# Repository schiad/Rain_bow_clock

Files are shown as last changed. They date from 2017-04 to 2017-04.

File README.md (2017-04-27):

   ╔════════════════════╗ ╔════════════════════╗ ╔════════════════════╗ ╔════════════════════╗
   ║JEUDI    01 JAN 1970║ ║01/01/1970  00:03:00║ ║01/01/1970  00:28:33║ ║JEUDI    01 JAN 1970║
   ║                    ║ ║←       HELP       →║ ║   Neopixel Hello   ║ ║                    ║
   ║      00:59:58      ║ ║--------------------║ ║>   Crash Clock    <║ ║01/01/1970  00:00:00║
   ║                    ║ ║Obtain usage advice.║ ║     Toggle LCD     ║ ║                    ║
   ╚════════════════════╝ ╚════════════════════╝ ╚════════════════════╝ ╚════════════════════╝

# Rainbow Clock Project Pinout

      ______________________________________________________________________________________
     |      Module      |   Pins    |        Pin designator(s)       |        Notes         |
     |__________________|___________|________________________________|______________________|
     | 1x Temperature   |         2 | SCL1, SDA1                     | Uses I2C.            |
     |__________________|___________|________________________________|______________________|
     | 1x Bluetooth     |         2 | RPB6*, RPA0*                   | Uses UART.           |
     |__________________|___________|________________________________|______________________|
     | 1x Led strip     |         1 | RC4                            | Single pin, 60 leds. |
     |__________________|___________|________________________________|______________________|
     | 1x LCD Screen    |        10 | RB10..RB15, RC0, RC1, RB2, RB3 | xxxxxxxxxxxxxxxxxxxx |
     |__________________|___________|________________________________| xxxxxxxxxxxxxxxxxxxx |
     | 1x Light sensor  |         1 | AN1                            | xxxxxxxxxxxxxxxxxxxx |
     |__________________|___________|________________________________| xxxxxxxxxxxxxxxxxxxx |
     | 1x ICD           |         3 | PGEC1, PGED1, MCLR             | xxxxxxxxxxxxxxxxxxxx |
     |__________________|___________|________________________________|______________________|
     | 1x LCD Backlight |         1 | RPC7*                          | Uses Output compare. |
     |__________________|___________|________________________________|______________________|
     | 3x Button        |     3 + 1 | INT0, RPC2*, RPC3*, RPC8*      | Uses NMI.            |
     |__________________|___________|________________________________|______________________|
     | 1x 8MHz Osc.     |         2 | OSC1, OSC2                     | xxxxxxxxxxxxxxxxxxxx |
     |__________________|___________|________________________________|______________________|
     | 1x 32kHz Osc.    |         2 | SOSCI, SOSCO                   | For the RTC.         |
     |__________________|___________|________________________________|______________________|
     | xxxxxxxxxxxxxxxx |         1 | RPC5*                          | Neopixel debug pin.  |
     |__________________|___________|________________________________|______________________|
     |        Total: 12 | Total: 29 |
     |__________________|___________|

     * pin is remappable for a function (Output compare, UART, SPI, NMI, etc...)

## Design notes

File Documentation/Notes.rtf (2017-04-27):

╔════════════════════╗
║JEUDI 01 JAN 1970║
║ ║
║ 00:59:58 ║
║ ║
╚════════════════════╝

╔════════════════════╗
║01/01/1970 00:03:00║
║← HELP →║
║--------------------║
║Obtain usage advice.║
╚════════════════════╝

╔════════════════════╗
║01/01/1970 00:15:17║
║ Neopixel Hello ║
║> Crash Clock <║
║ Toggle LCD ║
╚════════════════════╝

╔════════════════════╗
║01/01/1970 00:28:33║
║ ║
║01/01/1970 00:00:00║
║ ║
╚════════════════════╝

╔════════════════════╗
║01/01/1970 00:15:17║
║ Changing colors ║
║> Bluetooth sync <║
║ Setting the time ║
╚════════════════════╝

╔════════════════════╗
║Oops! That's a crash║
║Prepare for a reboot║
║EPC : 0x9D003EF8 ║
║Bus error ld/st ║
╚════════════════════╝

╔════════════════════╗
║01/01/1970 00:00:39║
║ ║
║01 01 0001 00 00 00║
║ d M Y h m s║
╚════════════════════╝

╚═MAIN═╗
╠═ABOUT═══╗
║ ╚═<plain template>
║
╠═ACTIONS═╗
║ ╠═Toggle_LCD
║ ╠═Crash_Clock
║ ╠═Neopixel_Hello
║ ╠═Reset_Clock
║ ╚═Say_Hello
║
╠═HELP════╗
║ ╠═Setting_the_time═╗
║ ║ ╚═<plain_template>
║ ║
║ ╠═Bluetooth_sync═══╗
║ ║ ╚═<plain_template>
║ ║
║ ╚═Changing_colors══╗
║ ╚═<plain_template>
╠═COLORS══╗
║ ╠═Background═══════╗
║ ║ ╚═<edit_template>
║ ║
║ ╠═Foreground═══════╗
║ ║ ╚═<edit_template>
║ ║
║ ╚═Markers══════════╗
║ ╚═<edit_template>
╚═TIME════╗
╚═<edit_template>

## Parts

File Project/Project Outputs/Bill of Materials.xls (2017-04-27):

Comment | Description | Footprint | Quantity | Fabricant | Fournisseur | RefFabricant | RefFournisseur
0.47uF | Capacitor | CAP0603 | 1
1-215876-3 | Tyco 1-215876-3 | 1-215876-3 | 1 | TE Connectivity | Farnell | 1-215876-3 | 1773039
10uF | Capacitor | CAP0603 | 1
1K | Inductor | IND0603 | 1 | Murata | Farnell | BLM18TG102TN1D | 1115051
1uF | Capacitor | CAP0603 | 1
22uF | Capacitor | CAP0603 | 1
32kHz XTAL | Crystal Oscillator | NCL38LF | 1 | Fox Electronics | Farnell | NC38LF-327 | 2064058
8MHz XTAL | Crystal Oscillator | FOXSLF/080-20 | 1 | Fox Electronics | Farnell | FOXSLF/080-20 | 2057960
AC to DC adapter | Power adapter |  | 1 | IDEAL POWER | Farnell | 25HK-AB-050A400-CP | 2334613
BMP280 | Temp. sensor |  | 1 | BOSCH |  | BMP280
EC11B152420G-STEC11B01 | Rotary encoder | EC11B152420G-STEC11B01 | 1 | ALPS | Farnell | EC11B152420G-STEC11B01 | 1191733
HC-06 | Bluetooth |  | 1 | Wavesen |  | HC-06
Header 16 | Header, 16-Pin | Header 16 | 1 | SAMTEC | Farnell | CES-116-01-T-S | 1667522
LDR | Photoresistor | VT935G | 1 | Excelitas Tech | Farnell | VT935G | 1652638
MC42003A6W-BNMLW | LCD | MC42004A6W-BNMLW | 1 | MIDAS | Farnell | MC42004A6W-BNMLW | 2063162
PIC32MX110F016D-I/PT | Microcontroller | PIC32MX110F016H-I/PT | 1 | Microchip | Farnell | PIC32MX110F016D-I/PT | 2057068
PWR2.5 | Low Voltage Power Supply Connector | MJ-179PH | 1 | MULTICOMP | Farnell | MJ-179PH | 1737246
TS2940CP-3.3 C5 | Voltage Regulator | TS2940CP-3.3 C5 | 1 | TAIWAN SEMICONDUCTOR | Farnell | TS2940CP-3.3 C5 | 7261390
15pF | Capacitor | CAP0603 | 2
27pF | Capacitor | CAP0603 | 2
3306P-1-203 | Trimpot | 3306P-1-202 | 2 | Bourns | Farnell | 3306P-1-203 | 108240
Header 6 | Header, 6-Pin | Header 6 | 2 | MULTICOMP | Farnell | 2212S-06SG-85 | 1593462
SW-PB | Switch | 1-1825027-4 | 2 | TE Connectivity | Farnell | 1-1825027-4 | 2468742
4.7K | Resistor | RES0603 | 3
1K | Resistor | RES0603 | 4
WS2012B | Neopixel | WS2812b | 60 | WorldSemi |  | WS2812b
100nF | Capacitor | CAP0603 | 63

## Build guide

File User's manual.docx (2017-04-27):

Rainbow Clock

Electronics

User’s manual

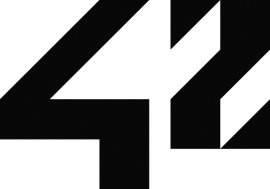
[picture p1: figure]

Document Revision. D

# Table of contents

# Glossary

## 1. Microcontroller

An embedded computer integrating a whole range of peripherals in a small package for convenience.

## 2. Bluetooth

A wireless communication standard permitting short-range exchange of data between electronic devices.

## 3. Refresh rate

A measure of the number of times an image can be drawn completely over the period of a second; this value is expressed in Hertz. Synonymous to “FPS”.

# Product overview

## 1. Description

Rainbow Clock is an unusual timekeeping device characterized by an exotic look and designed with electronics in mind.

## 2. Capabilities

- Display the current time of the day
- Synchronize itself via a Bluetooth connection
- Alter its color scheme depending on events

## 3. Quick specs

- Microcontroller: PIC32MZ series
- LEDs: 60, RGB type
- Refresh rate: ~10Hz
- Power: 15Watt max, 0.5Watt minimal, 0.6Watt typical (measured on a prototype)

# Basic operation

## 1. Reading the time of day

Each color encodes a distinct time unit. For each unit:

- 3 red adjacent LEDs represent the hours.
- 2 green adjacent LEDs represent the minutes.
- The remaining blue LED represents the seconds.

To ease reading, the clock’s display is subdivided in four quadrants.

## 4. Changing the color scheme

Using the central dial, navigate the menu looking for “Color Config.”

Validate your choice. You will be presented with a choice of colors on the screen. Use the dial again, select a color and validate your choice.

## 5. Updating the time on the clock

Using the central dial, navigate the menu looking for “Time Config.”

Validate your choice.

# Advanced operation

## 1. Synchronizing the clock using Bluetooth

Initiate a serial connection to the Rainbow Clock’s Bluetooth module configured for a rate of 115200 bauds. The code to be sent is structured as follows:

“TssmmhhddMMYYYY”

With ‘T’ designating the Time config function.

# Technical details

## 1. Block diagram

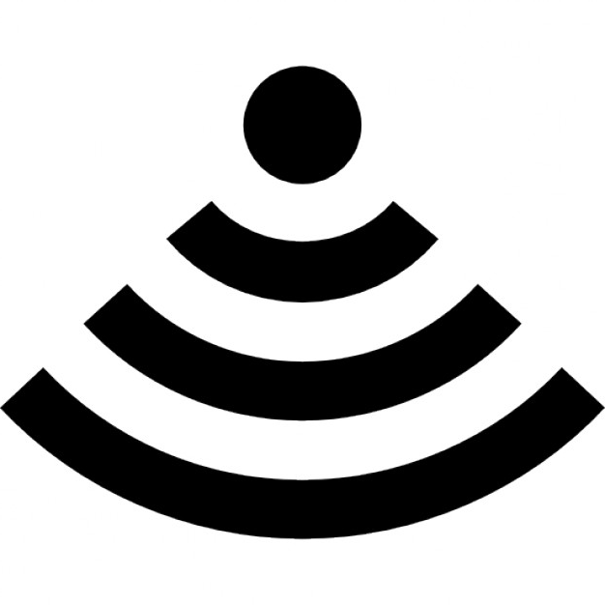
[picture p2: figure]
Afficher l'image d'origine
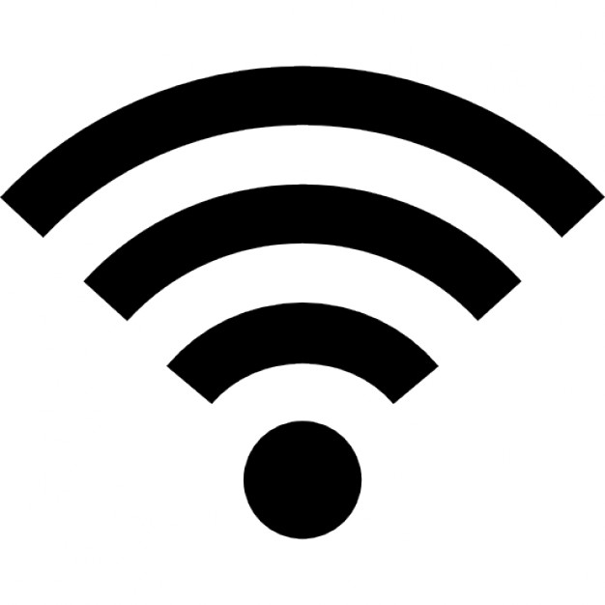
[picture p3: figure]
Afficher l'image d'origine

Light sensor (ADC)

Buzzer

(PWM)

PIC32

60 LEDs

(GPIO)

Bluetooth

(UART)

AC to DC Power supply

On/Off Button

Raspberry Pi *

Bluetooth

Smartphone *

Bluetooth

LCD Display
(GPIO)

Logging

(UART)

Buttons

(GPIO)

Temperature and pressure sensor (SPI)

## 4. Electrical consumption

- LEDs: Between 3.5V - 5.3V, about 60mA, 60mA x 60 = 3.6A max.
- PIC32: Between 2.3V - 3.6V, about 100mA.
- BMP280: Between 1.71V - 3.6V, about 4.2µA.
- RN4020: Between 3.0V – 3.6V, current is between 8mA 40mA.

In line 3.3V the consumption of current is about 141mA, in line 5V current consumption is about 3.6mA maximum, the total consumption is 3.741A maximum.

## 5. Components required for the project

- 1 (one) PIC32xxxxxx microcontroller. Ref: xxxxxxx
- 1 (one) Strip of 60 RGB LEDs. Ref fab: WS2812b
- 1 (one) Incremental rotary encoder Ref: 1191733
- 1 (one) 20x4 alphanumeric LCD screen Ref: 2063162
- x (xxx) Resistors xΩ Ref: xxxxxxx
- x (xxx) Capacitors xF Ref: xxxxxxx
- 1 (one) Voltage regulator Ref: xxxxxxx
- 1 (one) Digital pressure and temp sensor Ref fab: BMP280
- 1 (one) Bluetooth communication module Ref: 2442930
- 1 (one) 5v Supply Ref: xxxxxxx
- 1 (one) Photocell Ref: 7482280
- 1 (one) buzzer Ref: 2361105
- 2 (two) push buttons Ref: 1550267

…

We decided to use WS2812b as our LEDs for their convenience (They can be driven with a single wire using a simple protocol described in the datasheet of the component). (Not going to be bought from Farnell)

For our sensor, we chose the BMP280 or the BME280. It provides both temperature / pressure measurements and uses the I²C or SPI protocol. (Not going to be bought from Farnell).

A photoresistor will be used in a voltage divider setup, connected as an analog input pin.

We chose a rotary button for most of the interfacing with the clock. On the plus side, any watch user will figure out its multiples purposes.

Uses two GPIO plus two other GPIO buttons.

We are using a “Serial to Bluetooth” module for the device to communicate with smartphones and computers, so as to avoid the potential complexity of implementing a full Bluetooth stack, which we can’t afford at this time.

The chosen power supply can deliver up to 4A at 5v, and will still support the charge with all LED set at their maximum brightness level.

The chosen voltage regulator can deliver up to 1A in 3.3v for electronic modules using this amount of voltage.

## 6. Communications protocols used

### 1. UART

UART (or Serial) is a communication protocol, to use a same speed between PIC and Bluetooth we have choose 115200 bauds, in 8 bits mode, 1 Bit for stop, it will be used on Half Duplex mode.2.

### 2. I2C

The I2C protocol is essentially a bus made of 2 wires, SDA and SCL. SCL (serial clock line) is the clock speed for communication (the master imposes it), SDA (serial data line) is the line reserved for data transmissions.

I2C is a master-slave protocol. When a master starts to communicate, all others peripherals must stand by for instructions. The master first sends the starting bit, calling a slave peripheral by its address, before mentioning whether it wants to read or write data from it, then communicates the internal address of data.

For reading, the master sends SCL clock and reads back data sent by the slave peripheral via the SDA wire. If master is writing data in slave peripheral master will impose SCL clock and SDA data to write in slave. Of course each peripheral have a single addresses coded in 7 bits and each of them can be a master or slave.

### 3. SPI

The SPI protocol is a communication bus composed by 4 wires, SCLK (clock rate speed transfer), MOSI (communication from master to slave), MISO (communication for slave to master, and SS (slave selection).

The master selects a slave with SS wire by connect the line in GND, and initialize the communication with slave, master send data with MOSI line and slave respond with MISO line, slave and master can communicate in same time (full duplex communication).

## 7. Implementation

We want to make the rainbow clock really different of other clock we imagine to make it hexagonal form in front all LED’s and LCD display, in read all other components.

THU Mar 3 2016

PCB

LED

BUTTON

LCD

# Planned features

- Display basic weather data and forecast using built-in sensors

Data gathering could reveal itself being a nice addition to the project.

# Contributions

In alphabetical order:

- ltesson ltesson@student.42.fr
- nahmed-h nahmed-h@student.42.fr
- schiad schiad@student.42.fr
- vchesnea vchesnea@student.42.fr

Page layout by: vchesnea

# Endnotes

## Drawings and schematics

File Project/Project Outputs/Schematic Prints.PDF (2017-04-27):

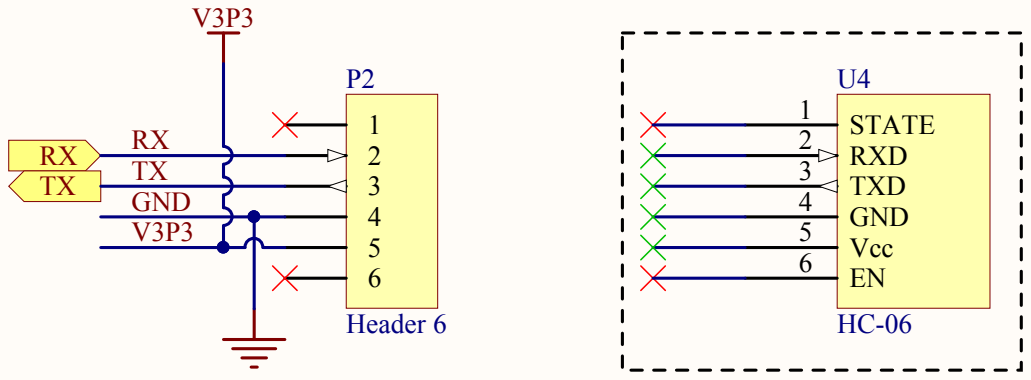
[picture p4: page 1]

Title | ****

Serial to Bluetooth module *

Size: A4 | Number: | Revision:
Date: 26/06/2016 Time: 15:38:15 | | Sheet * of

C:\Users\bocal\Desktop\RainbowClockV3\Project\Schematics\Bluetooth.SchDoc
File:

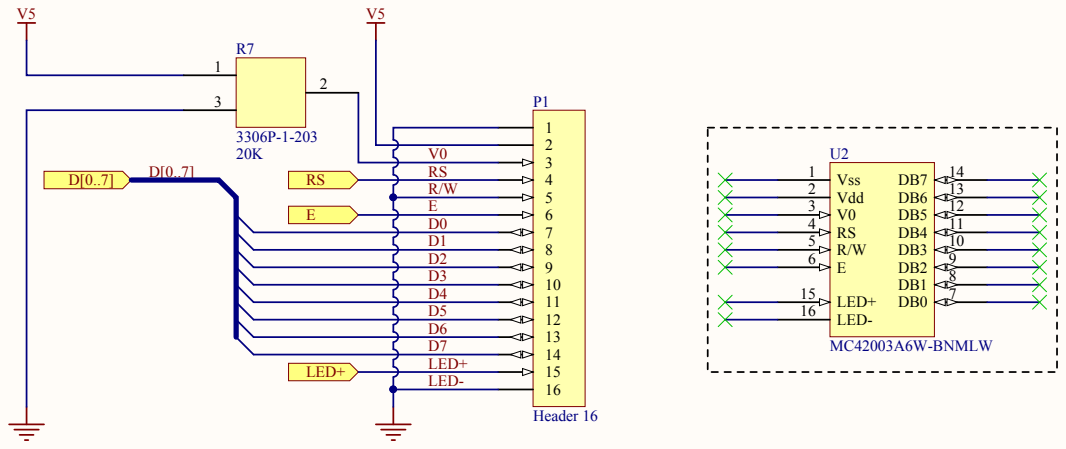
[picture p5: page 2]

C:\Users\bocal\Desktop\RainbowClockV3\Project\Schematics\LCD.SchDoc

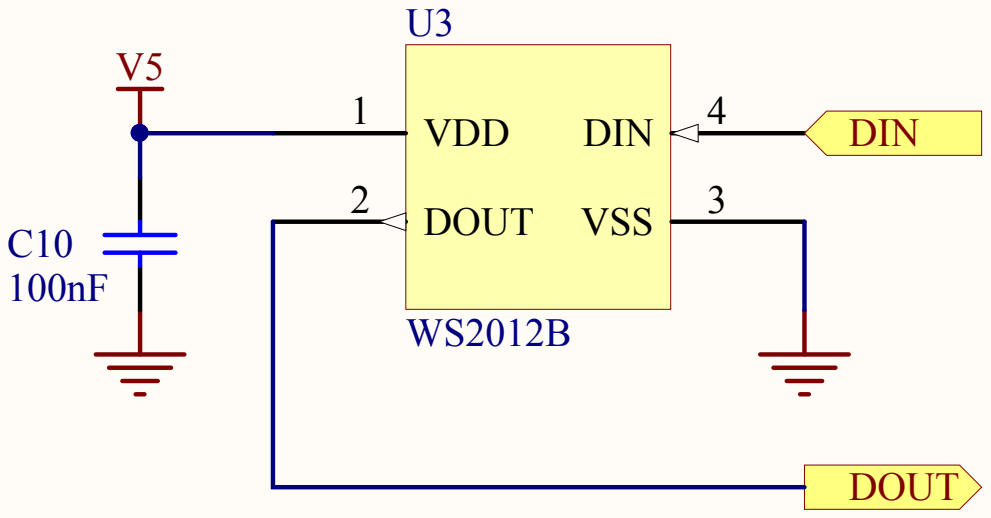
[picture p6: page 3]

Title Neopixel | * * *

C:\Users\bocal\Desktop\RainbowClockV3\Project\Schematics\Neopixel.SchDoc

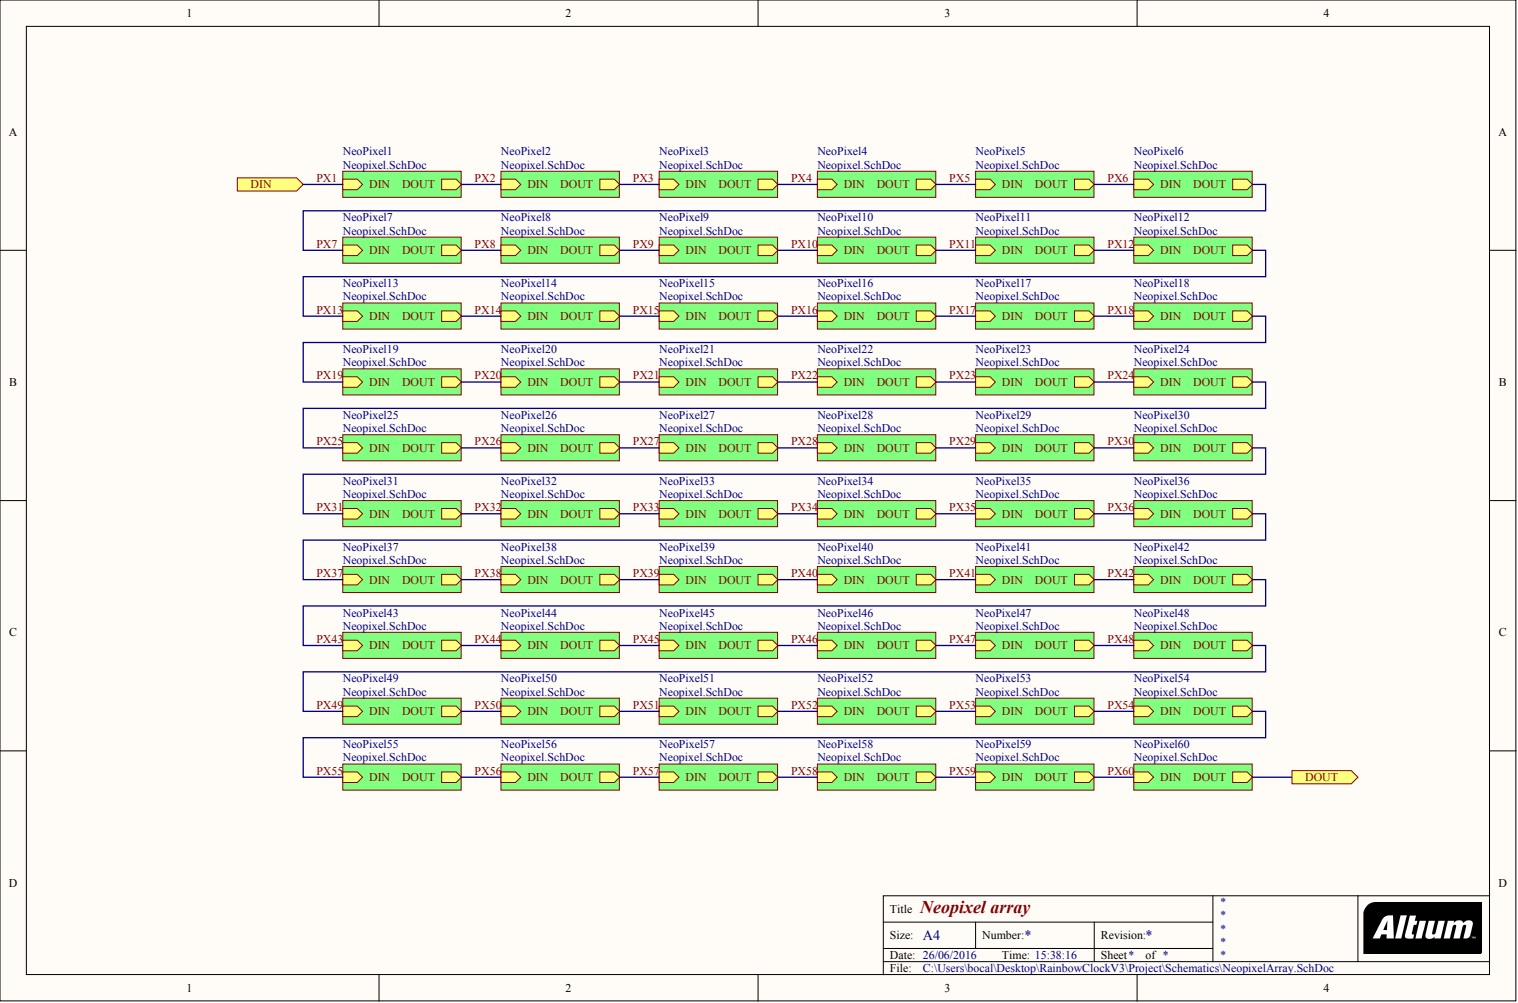
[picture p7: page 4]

Title Neopixel array | * * *

C:\Users\bocal\Desktop\RainbowClockV3\Project\Schematics\NeopixelArray.SchDoc

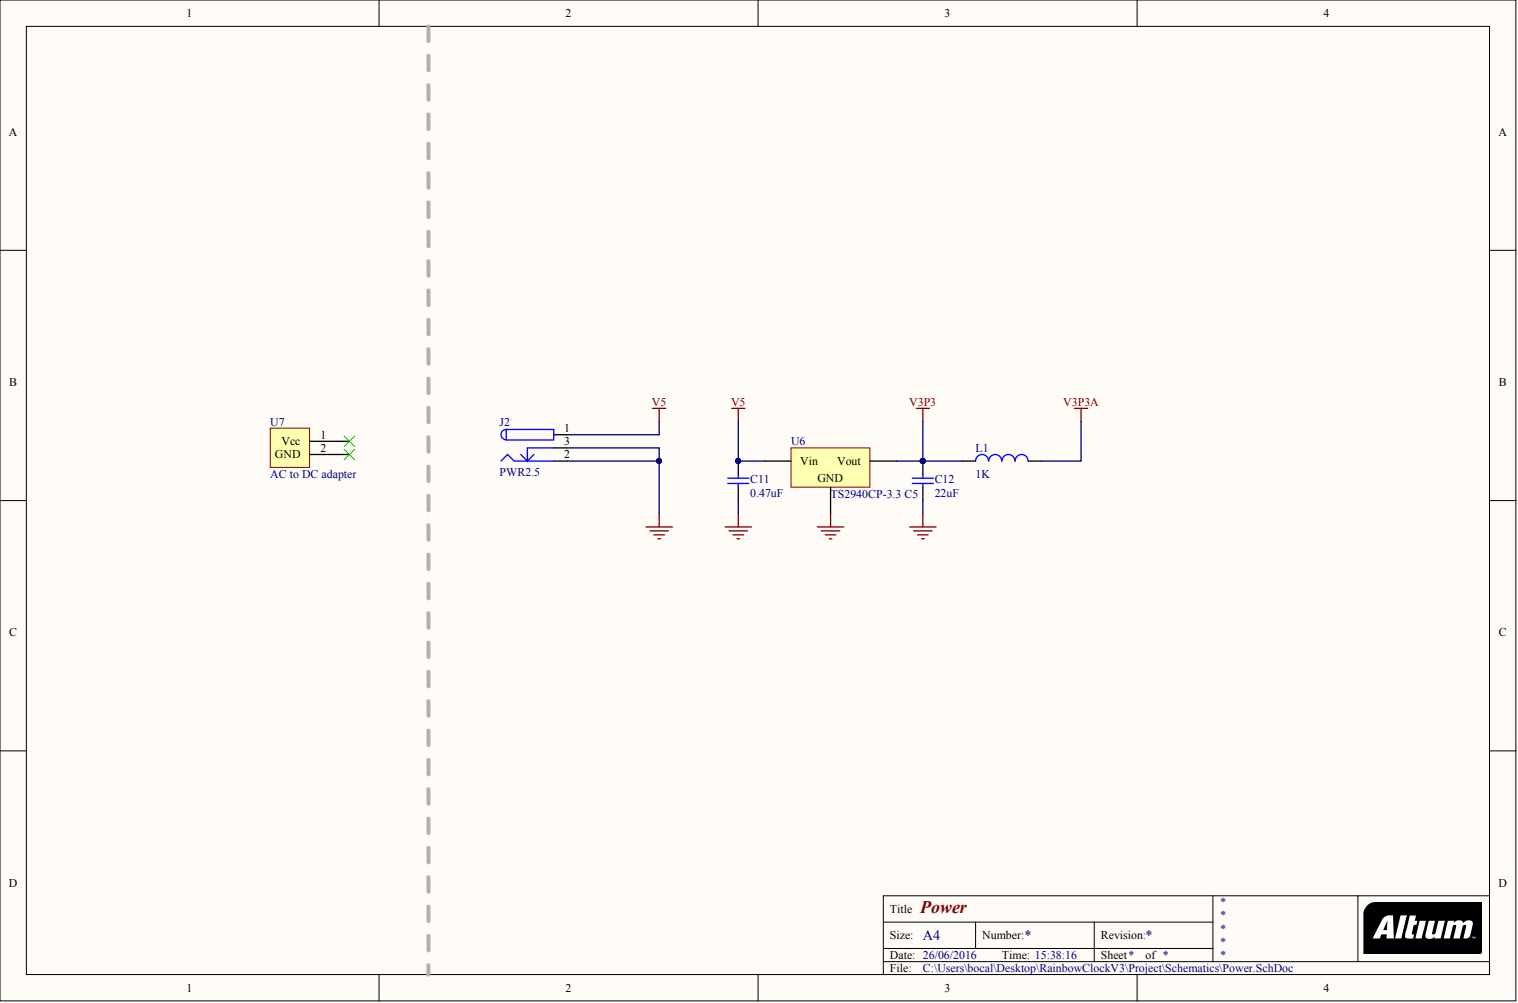
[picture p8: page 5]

C:\Users\bocal\Desktop\RainbowClockV3\Project\Schematics\Power.SchDoc

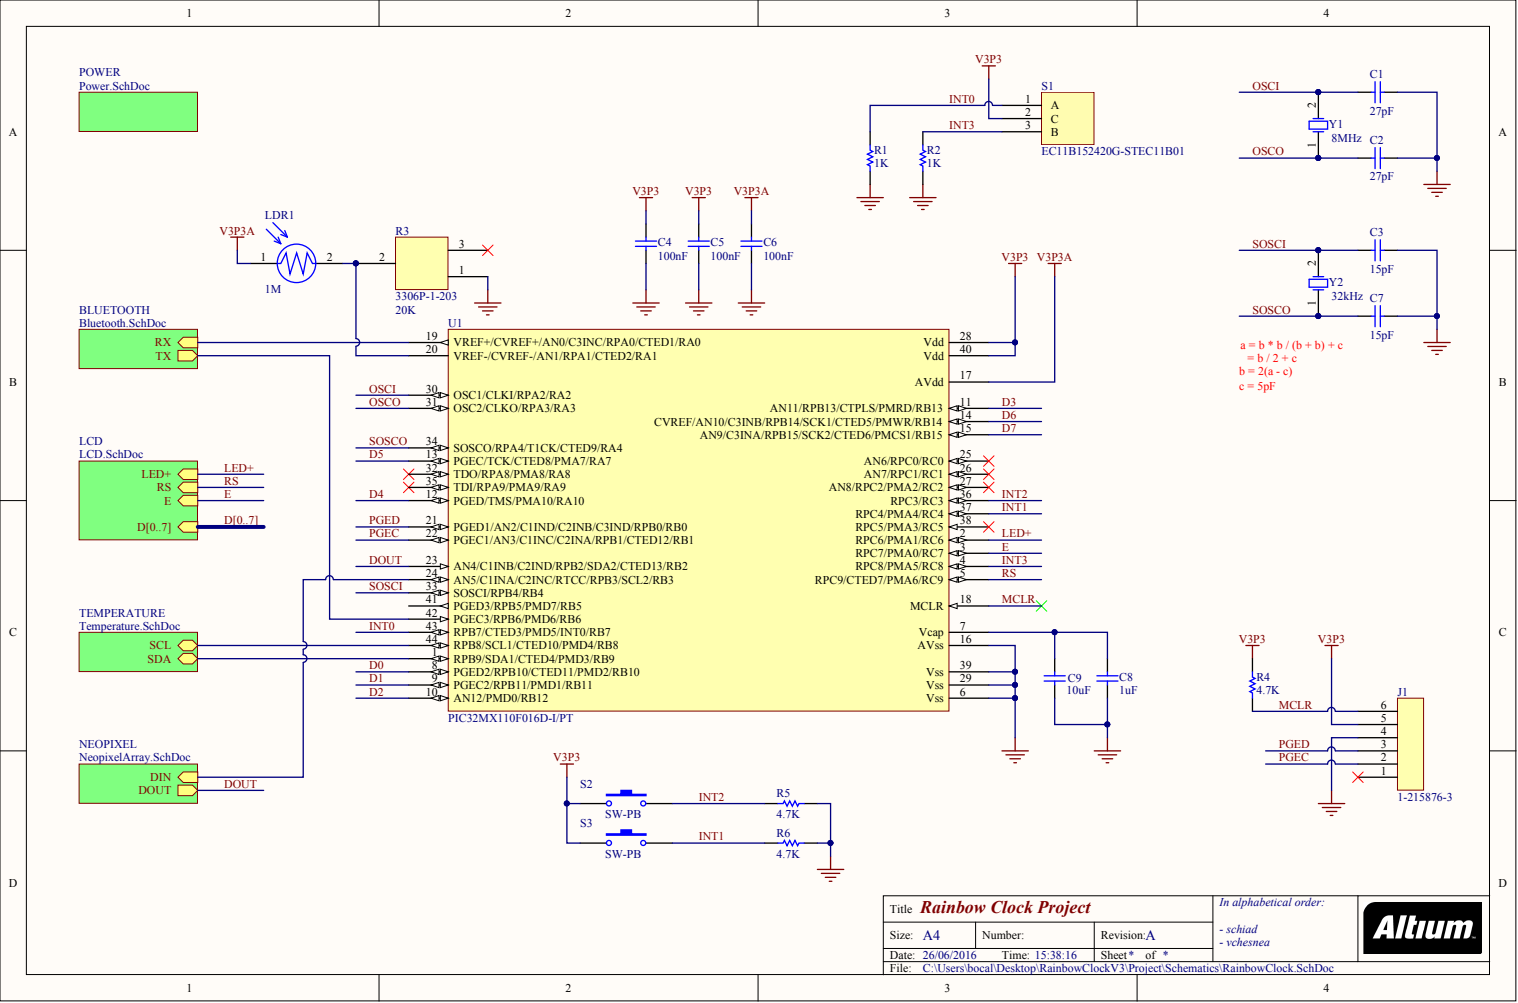
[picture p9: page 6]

Title Rainbow Clock Project | In alphabetical order: - schiad - vchesnea

C:\Users\bocal\Desktop\RainbowClockV3\Project\Schematics\RainbowClock.SchDoc

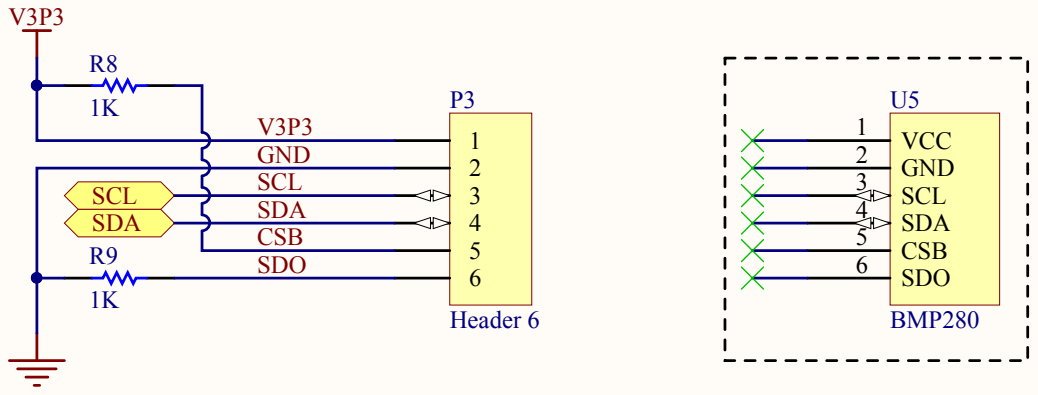
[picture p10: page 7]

C:\Users\bocal\Desktop\RainbowClockV3\Project\Schematics\Temperature.SchDoc

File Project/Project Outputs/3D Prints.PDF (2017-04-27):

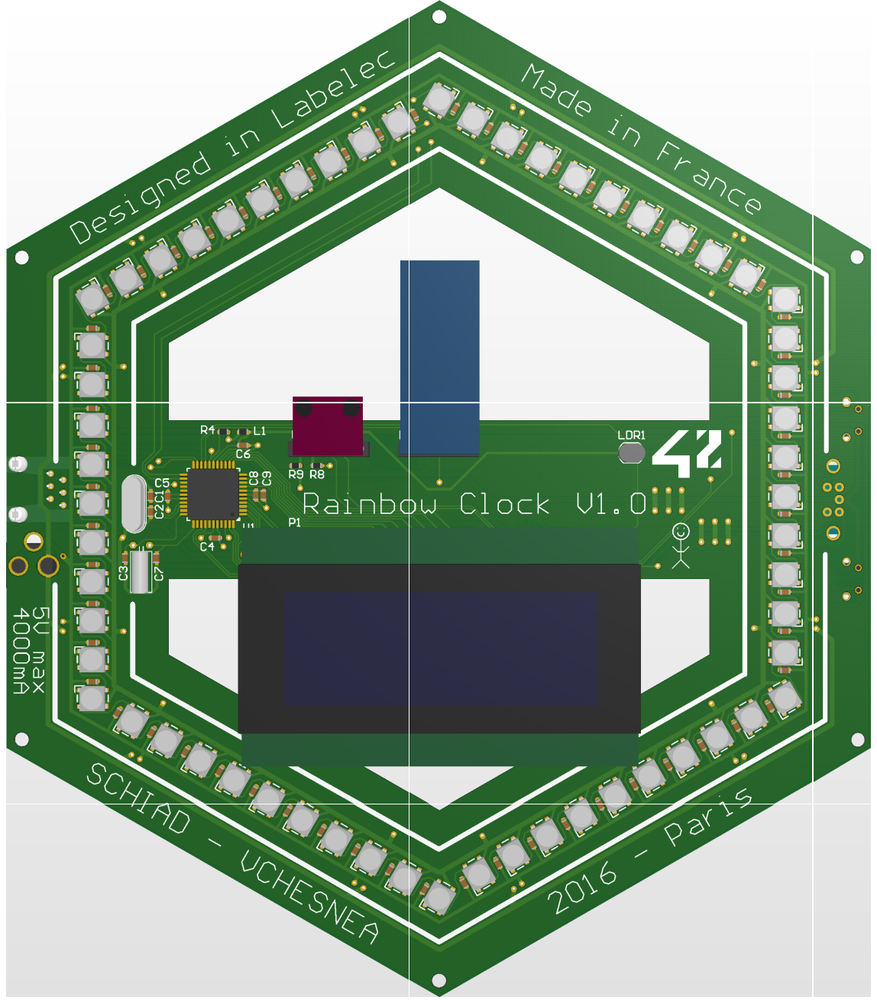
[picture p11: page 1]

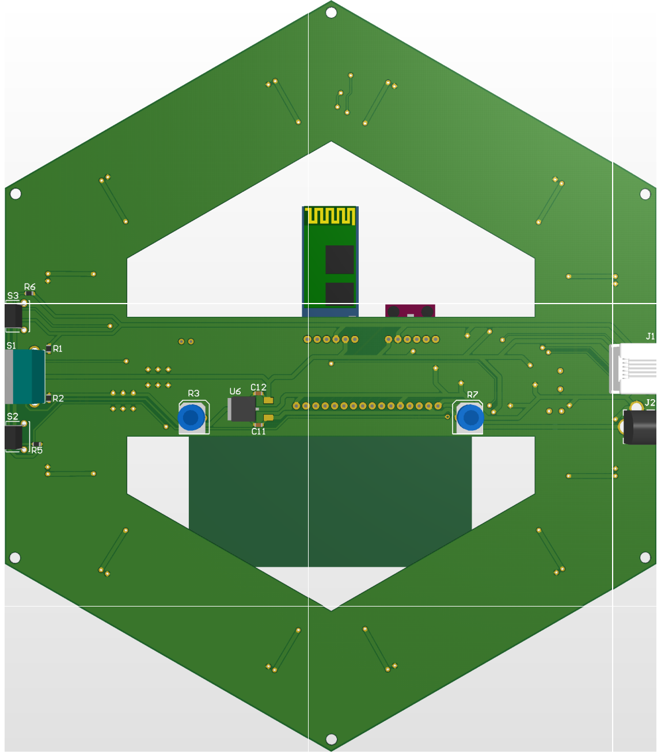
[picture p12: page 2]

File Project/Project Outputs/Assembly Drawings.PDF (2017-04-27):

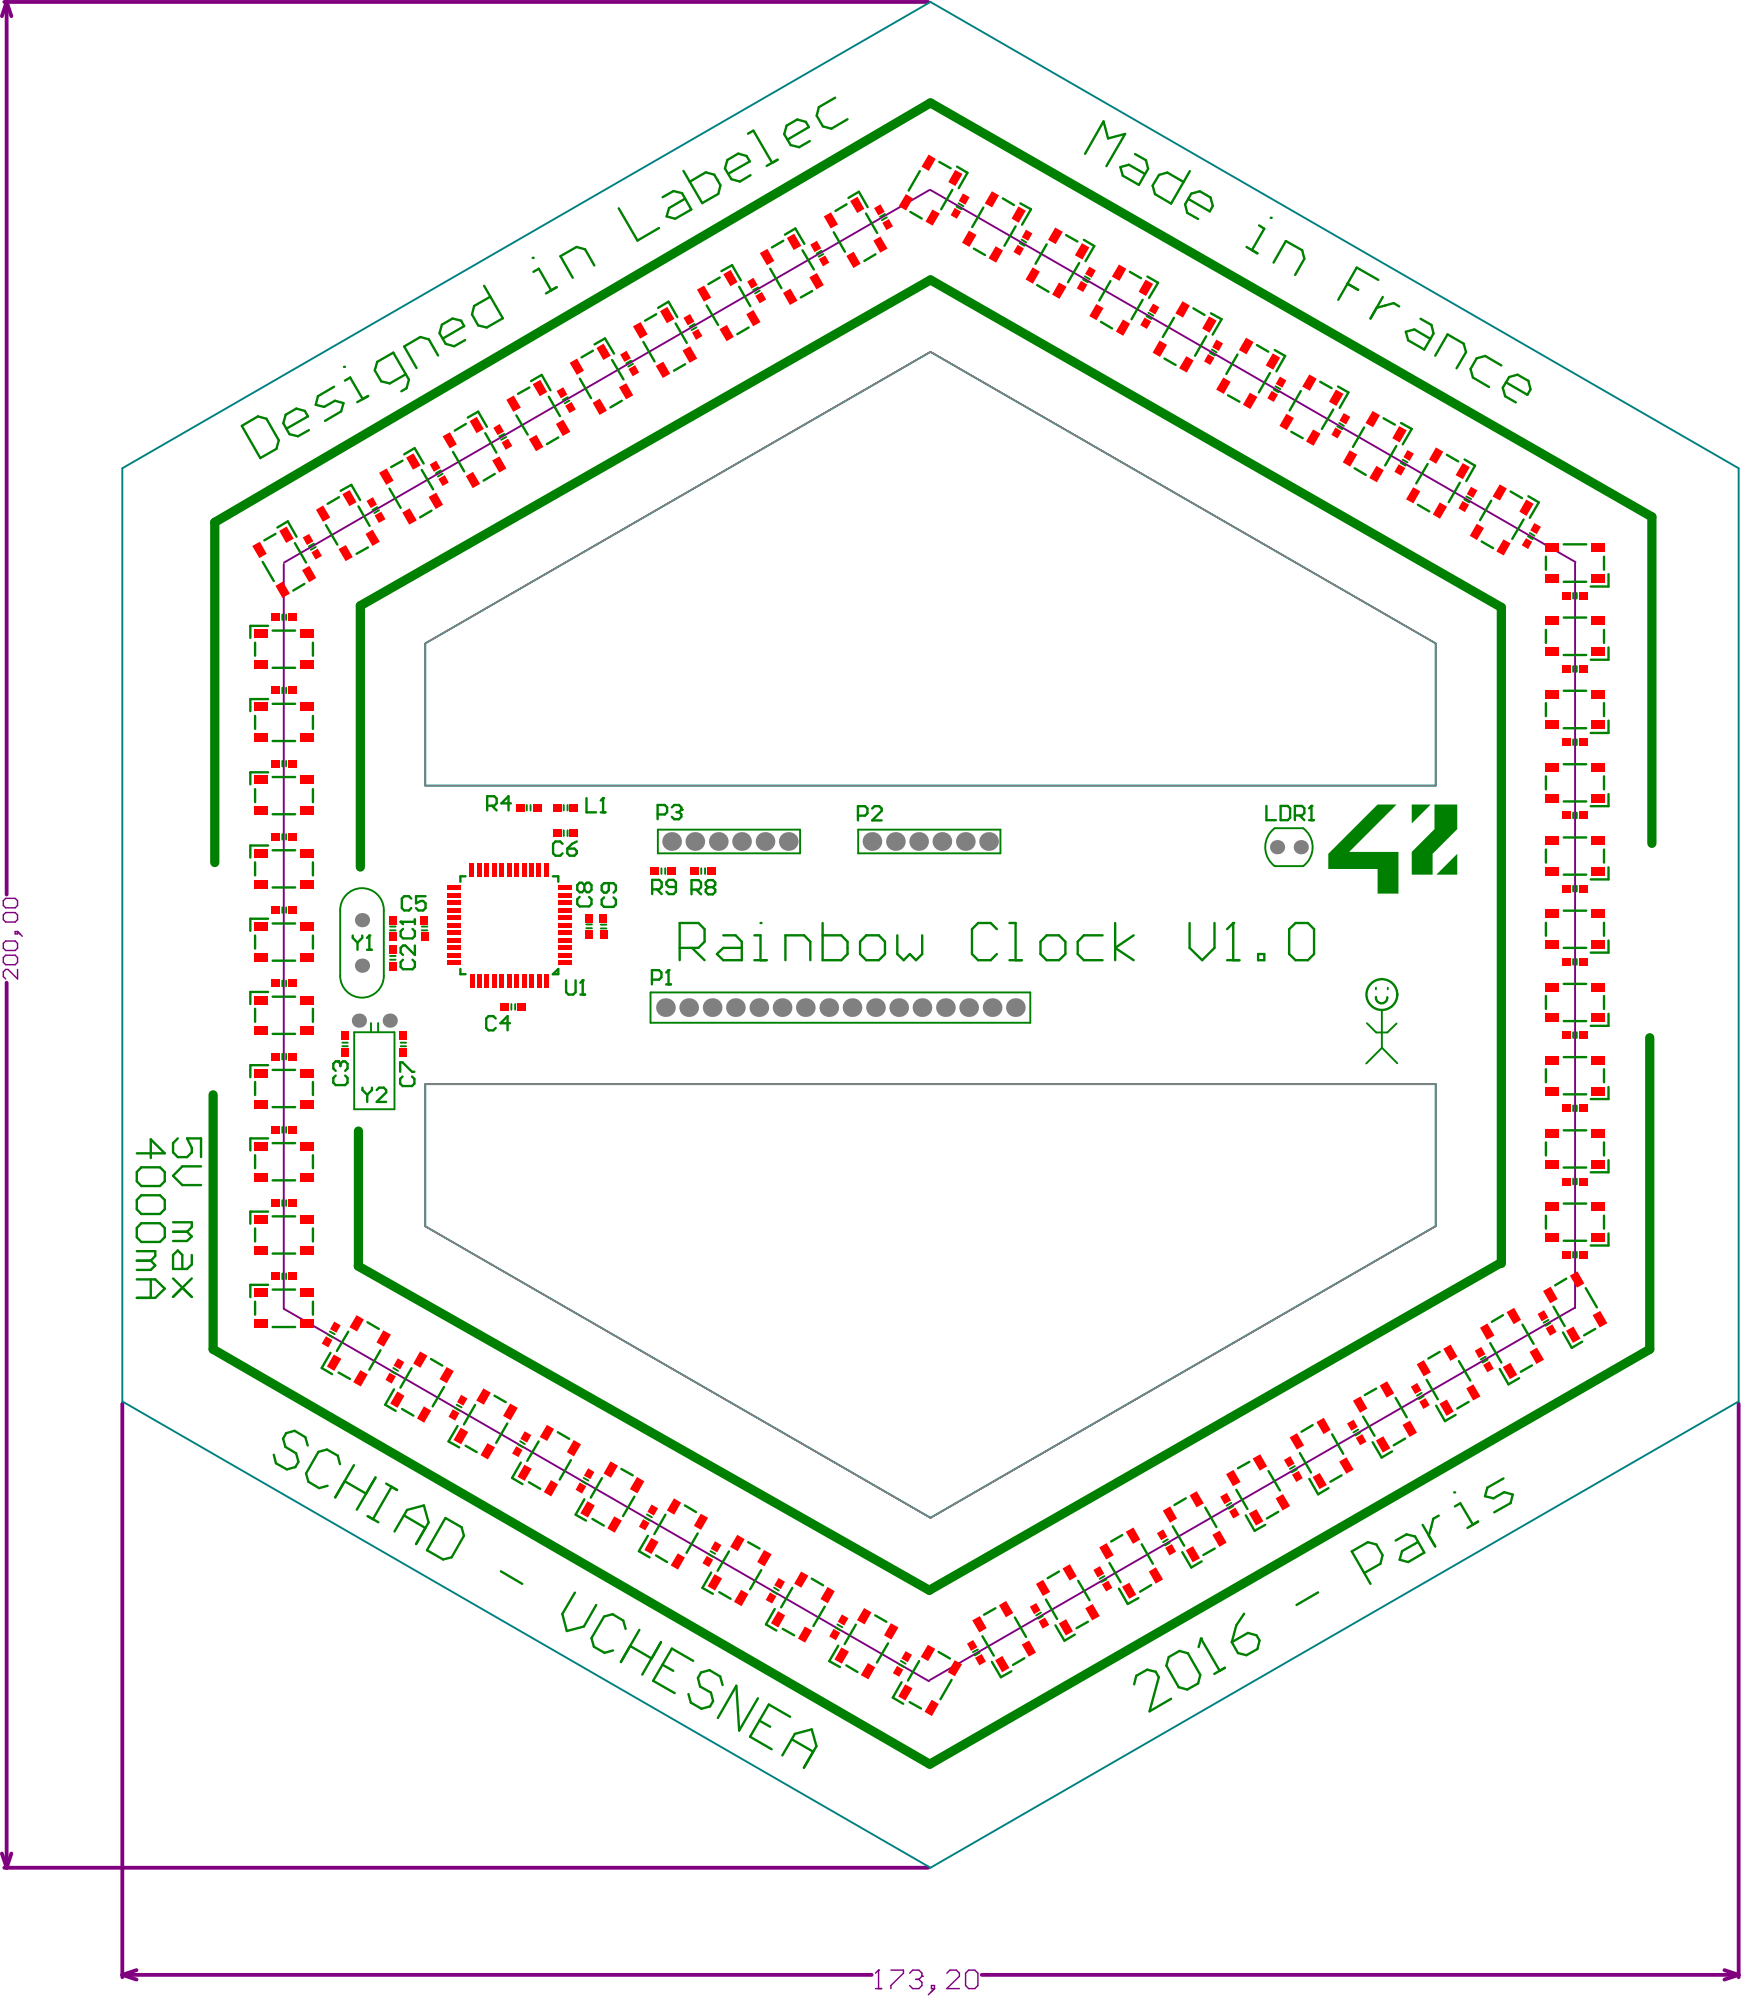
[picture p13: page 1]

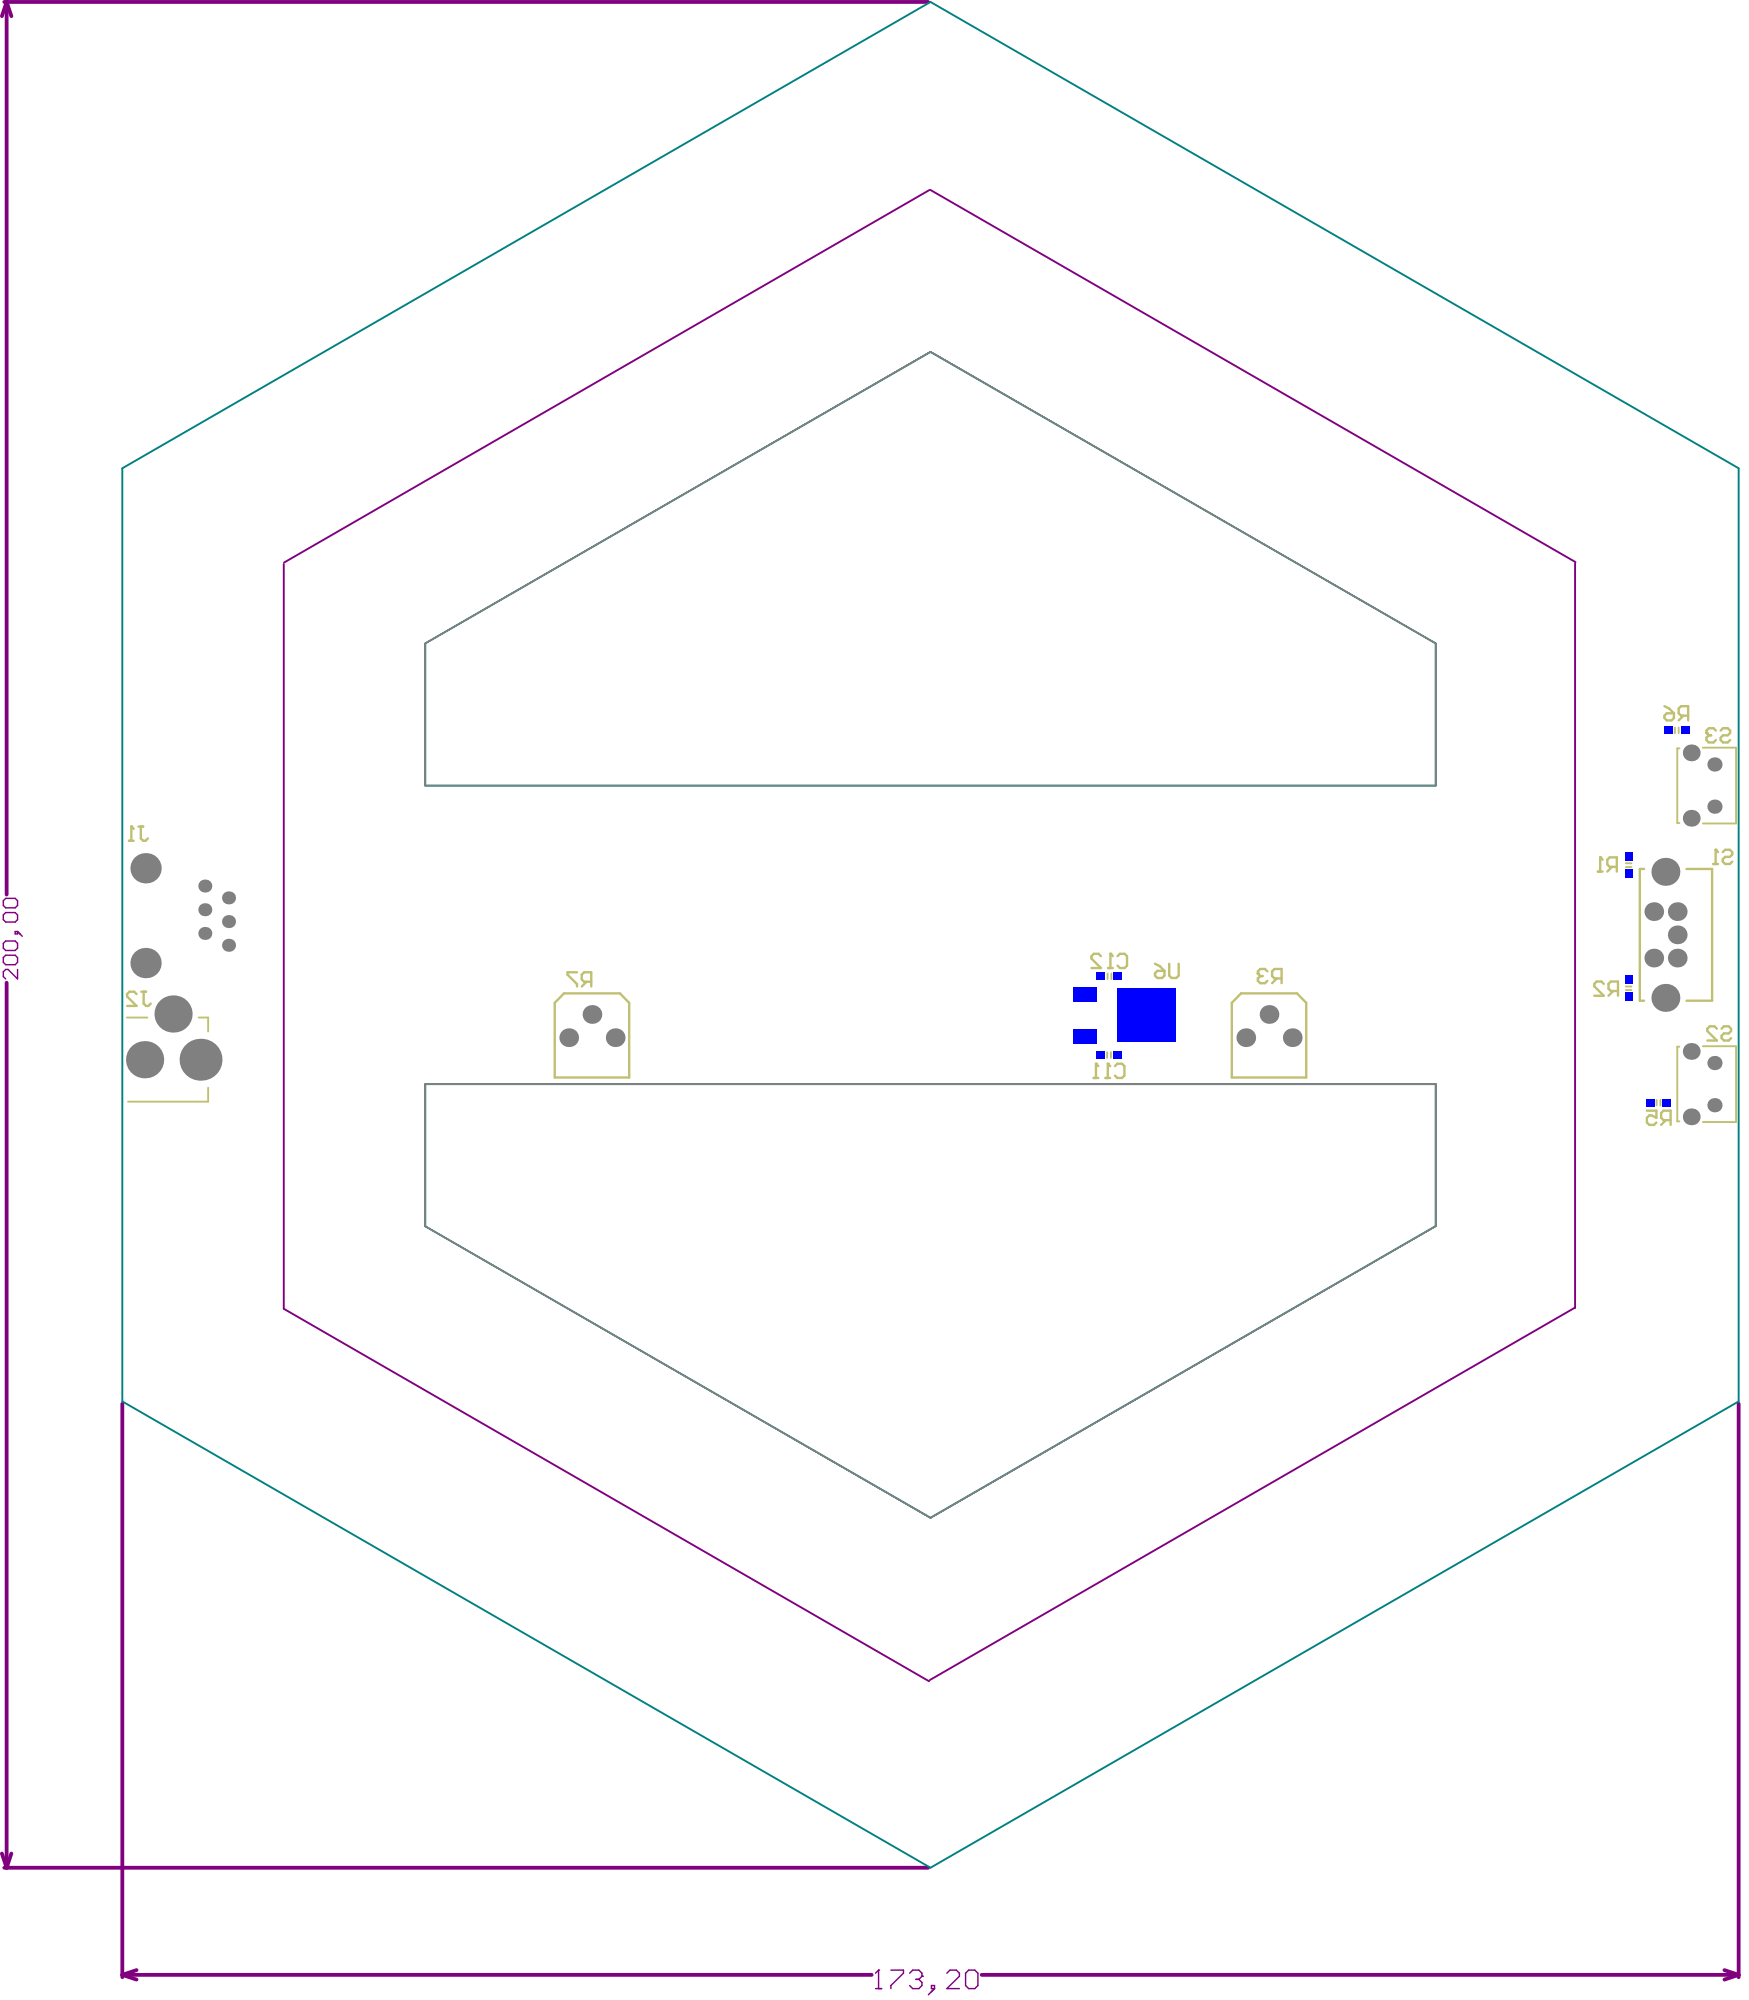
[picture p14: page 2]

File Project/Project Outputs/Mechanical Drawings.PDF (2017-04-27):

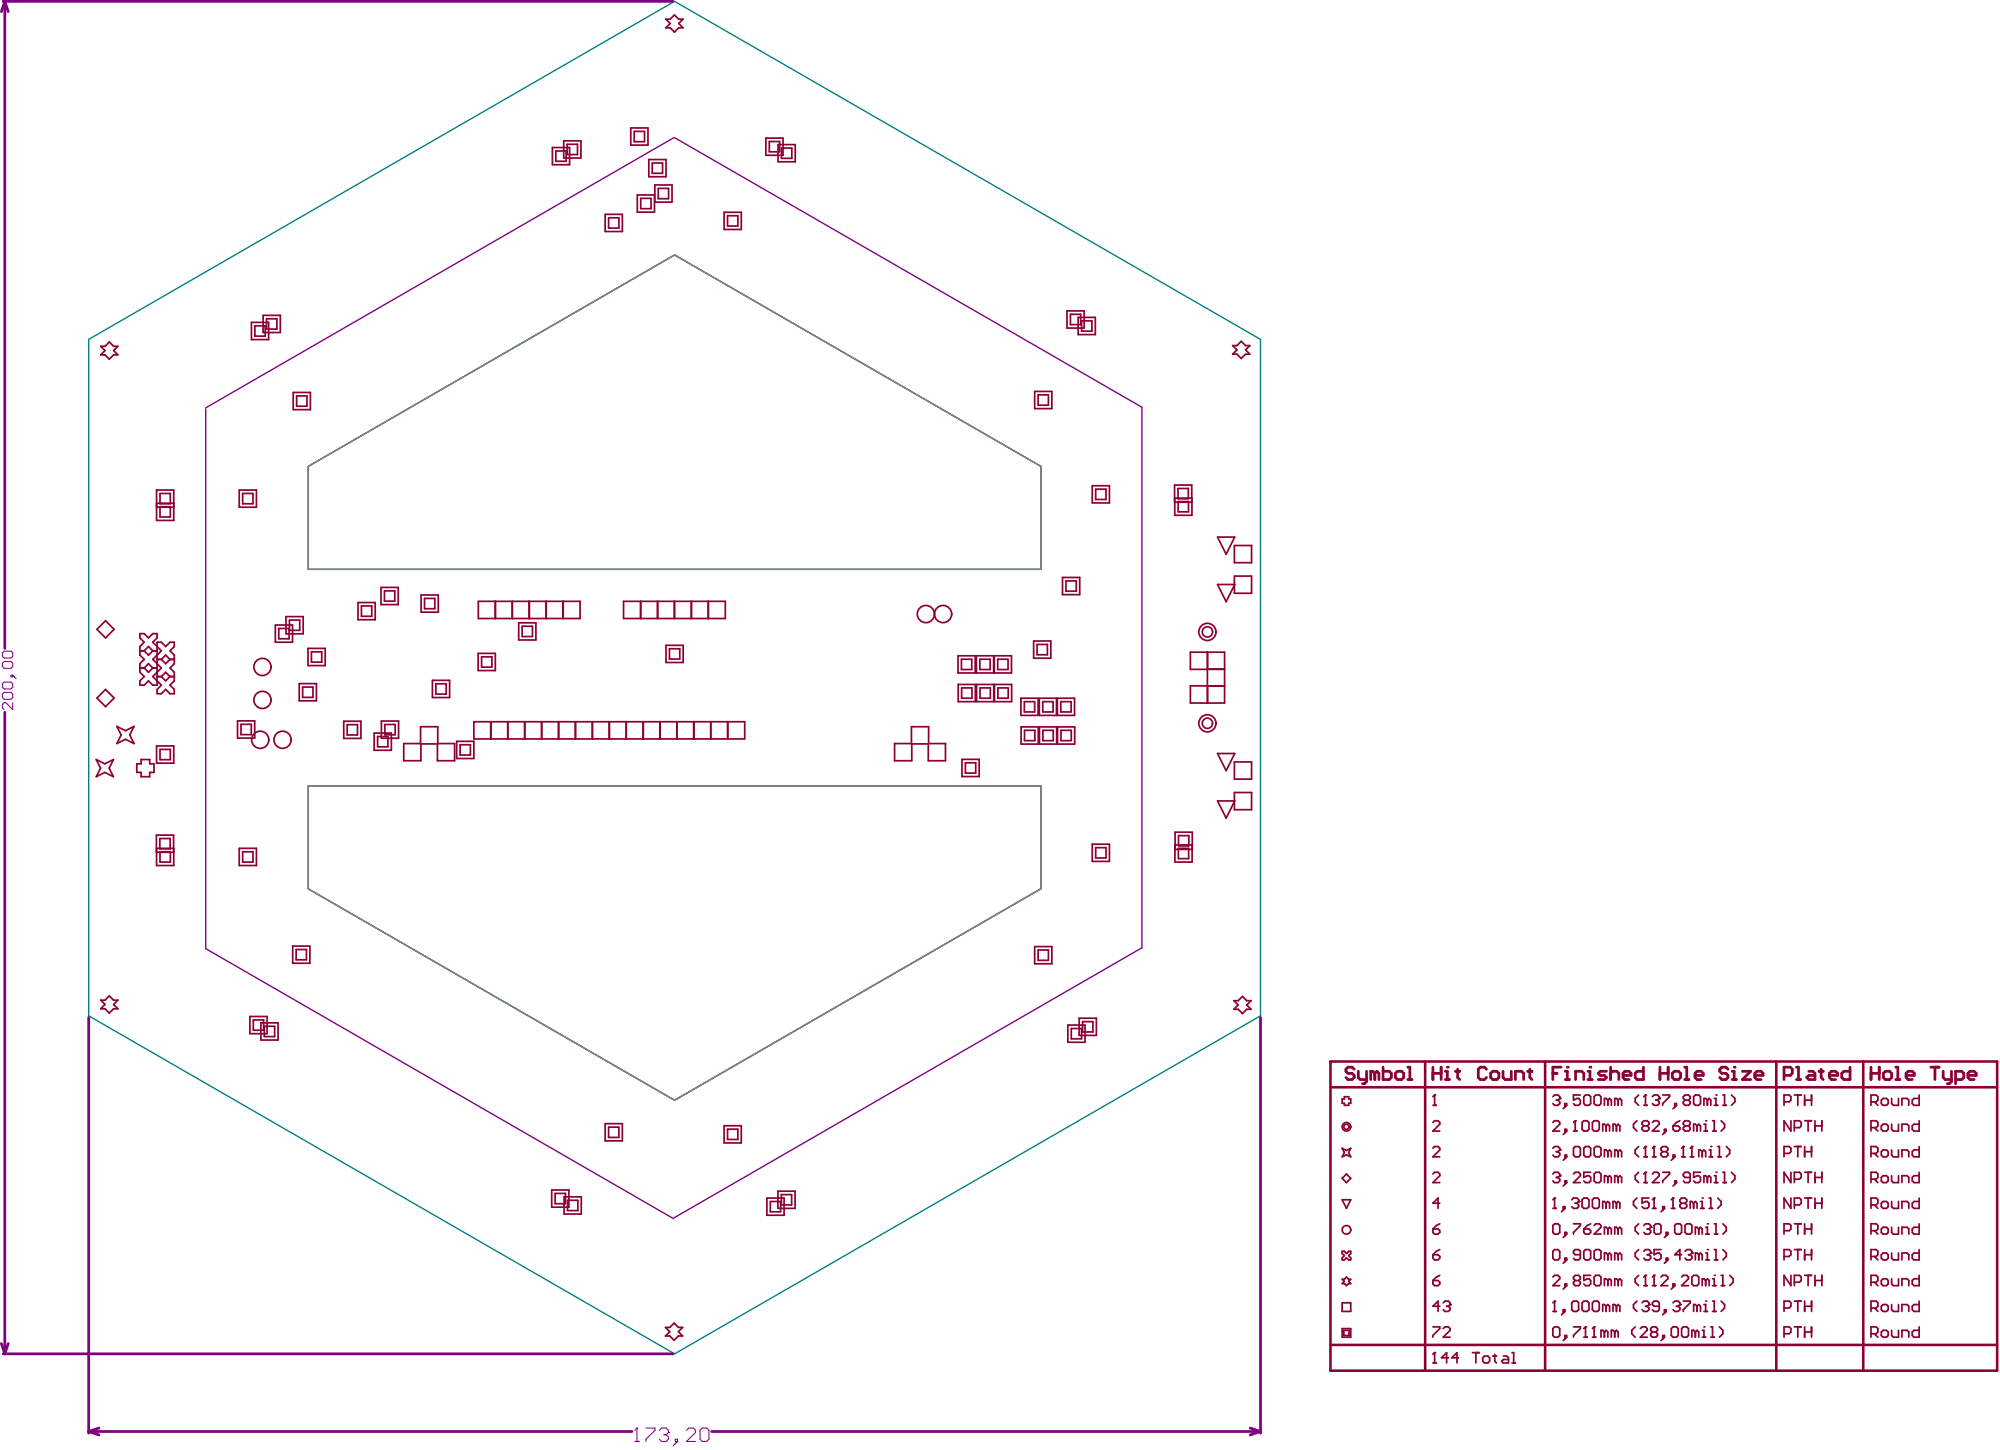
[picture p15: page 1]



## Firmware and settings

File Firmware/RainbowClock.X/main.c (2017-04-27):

/* TODO:
 * - Rewrite libpixel  OK
 * - Rewrite libuart   OK
 * - Rewrite liblcd    OK
 * - Rewrite libi2c    ??
 */

#include "rainbowclock.h"

DATE    date;
TASK    task;
LCD     *lcd;
MENU    *menu;
PIXEL   *pixels;

void ISR(_EXTERNAL_1_VECTOR,IPL6AUTO) button_enter(void)
{
    libsys_delay_millis(1); /* Workaround for button hysteresis */
    if (menu->curr != NULL) {
        switch (menu->curr->type) {
            case ITEM_HOOK:
                task.active = true;
                break;
            case ITEM_LINK:
                if (menu->curr->type == ITEM_EDIT)
                    liblcd_cursor(lcd, false);
                menu = menu->curr->data.link.addr;
                menu_update(menu, lcd);
                if (menu->curr->type == ITEM_EDIT)
                    liblcd_cursor(lcd, true);
                break;
            case ITEM_EDIT:
                liblcd_blink(lcd, true);
                menu->editing = true;
                break;
            default:
                break;
        }
    }
    IFS0bits.INT1IF = 0;
}

void ISR(_EXTERNAL_2_VECTOR,IPL6AUTO) button_cancel(void)
{
    libsys_delay_millis(1); /* Workaround for button hysteresis */
    if (menu->editing) {
        *menu->curr->data.edit.addr = menu->curr->data.edit.value;
        liblcd_blink(lcd, false);
        menu->editing = false;
    } else if (task.active) {
        task.message = MESSAGE_KILL;
    } else if (menu->parent) {
        if (menu->curr->type == ITEM_EDIT)
            liblcd_cursor(lcd, false);
        menu = menu->parent;
        menu_update(menu, lcd);
        if (menu->curr->type == ITEM_EDIT)
            liblcd_cursor(lcd, true);
    }
    IFS0bits.INT2IF = 0;
}

void ISR(_EXTERNAL_0_VECTOR,IPL6AUTO) encoder_next(void)
{
    EDIT    *edit;
    int     value, i;

    libsys_delay_millis(1);
    if (menu->curr) {
        if (menu->curr->type == ITEM_EDIT) {
            edit = &menu->curr->data.edit;
            if (menu->editing) {
                i = edit->col;
                for (value = 1; i; --i)
                    value *= 10;
                edit->value = MOD(edit->value - value, edit->max + 1);
            } else {
                if (edit->col <= 0 && menu->curr->prev)
                    menu->curr = menu->curr->prev;
                else
                    --edit->col;
            }
        } else if (menu->curr->prev) {
            if (task.active)
                task.message = MESSAGE_KILL;
            menu->curr = menu->curr->prev;
        }
        menu_update(menu, lcd);
    }
    INTCONbits.INT0EP ^= 1;
    INTCONbits.INT3EP ^= 1;
    IFS0bits.INT3IF = 0;
    IFS0bits.INT0IF = 0;
}

void ISR(_EXTERNAL_3_VECTOR,IPL6AUTO) encoder_prev(void)
{
    EDIT    *edit;
    int     value, i;

    libsys_delay_millis(1);
    if (menu->curr) {
        if (menu->curr->type == ITEM_EDIT) {
            edit = &menu->curr->data.edit;
            if (menu->editing) {
                i = edit->col;
                for (value = 1; i; --i)
                    value *= 10;
                edit->value = MOD(edit->value + value, edit->max + 1);
            } else {
                if ((edit->col + 1) >= edit->size && menu->curr->next)
                    menu->curr = menu->curr->next;
                else
                    ++edit->col;
            }
        } else if (menu->curr->next) {
            if (task.active)
                task.message = MESSAGE_KILL;
            menu->curr = menu->curr->next;
        }
        menu_update(menu, lcd);
    }
    INTCONbits.INT0EP ^= 1;
    INTCONbits.INT3EP ^= 1;
    IFS0bits.INT0IF = 0;
    IFS0bits.INT3IF = 0;
}

static void      poll_command(void)
{
    uint8_t  c, *s, b[8];

    if (libuart_getc(UART1, &c) && c == 'T')
    {
        libuart_gets(UART1, &s);
        date.seconds = 10 * (s[0]  - '0') + s[1]  - '0';
        date.minutes = 10 * (s[2]  - '0') + s[3]  - '0';
        date.hours   = 10 * (s[4]  - '0') + s[5]  - '0';
        date.day     = 10 * (s[6]  - '0') + s[7]  - '0';
        date.month   = 10 * (s[8]  - '0') + s[9]  - '0';
        date.year    = 1000 * (s[10] - '0') + 100 * (s[11] - '0')
            + 10 * (s[12] - '0') + (s[13] - '0');
        date.day_of_week = tondering_day_of_week(&date);
        libuart_puts(UART1, "Ok!\n");
        free(s);
    }
}

static void      processing_queue(void)
{
    while (true) {
        if (task.active == true) {
            menu->curr->data.hook.addr();
            task.message = MESSAGE_NONE;
            task.active = false;
        }
        poll_command();
        WDTCONbits.WDTCLR = 1; /* Give periodic life signs to the watchdog */
    }
}

void             main(void)
{
    initialize_system();
    menu_update(menu, lcd);
    processing_queue();
    while (1);
}

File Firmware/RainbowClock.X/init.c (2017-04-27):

#include "rainbowclock.h"

static bool initialize_ports(void)
{
    /* Neopixels, LCD, Encoder ---- */
    TRISC = 0xFFFFFD3F;
    TRISB = 0xFFFF0277;
    TRISA = 0xFFFFFB7F;
    /* UART1 ---------------------- */
    U1RXR =  0b001;         /* RX   */
    RPA0R =  0b001;         /* TX   */
    /* Buttons -------------------- */
    INT1R = 0b111;          /* RPC4 */
    INT2R = 0b111;          /* RPC3 */
    INT3R = 0b110;          /* RPC8 */
    /* ANALOG1 -------------------- */
    AD1CON1 = _AD1CON1_ON_MASK & ~_AD1CON1_ASAM_MASK
        | (4 << _AD1CON1_FORM_POSITION) & ~_AD1CON2_VCFG_MASK
        & ~_AD1CON2_BUFM_MASK & ~_AD1CON2_ALTS_MASK;
    AD1CHSbits.CH0SA = 1;
    return (true);
}

static bool initialize_devices(void)
{
    LCD_PINS pins = {
        {&LATC,  9}, {&LATC,  7},  {&LATB, 10}, /* RS, E,   D0, */
        {&LATB, 11}, {&LATB, 12},  {&LATB, 13}, /* D1, D2,  D3, */
        {&LATA, 10}, {&LATA,  7},  {&LATB, 14}, /* D4, D5,  D6, */
        {&LATB, 15}, {&LATC,  6}                /* D7, LED+     */
    };

    libsys_delay_micros(20000); /* Wait for the LCD to boot up*/
    if (!liblcd_new(&lcd, &pins, 20, 4))
        return (false);
    liblcd_display(lcd, true);
    liblcd_cursor(lcd, false);
    liblcd_light(lcd, true);
    libuart_begin(UART1, 9600);
    if (!libpixel_new(&pixels, &LATB, 3, 60))
        return (false);
    return (true);
}

static bool initialize_interrupts(void)
{
    /* Clock Tick    */
    IFS0bits.T1IF   = 0;
    IPC1bits.T1IP   = 7;
    IPC1bits.T1IS   = 0;
    IEC0bits.T1IE   = 1;
    /* Button ENTER  */
    IFS0bits.INT1IF = 0;
    IPC1bits.INT1IP = 6;
    IPC1bits.INT1IS = 0;
    IEC0bits.INT1IE = 1;
    /* Button CANCEL */
    IFS0bits.INT2IF = 0;
    IPC2bits.INT2IP = 6;
    IPC2bits.INT2IS = 0;
    IEC0bits.INT2IE = 1;
    /* Encoder PREV  */
    IFS0bits.INT0IF = 0;
    IPC0bits.INT0IP = 6;
    IPC0bits.INT0IS = 0;
    IEC0bits.INT0IE = 1;
    /* Encoder NEXT  */
    IFS0bits.INT3IF = 0;
    IPC3bits.INT3IP = 6;
    IPC3bits.INT3IS = 0;
    IEC0bits.INT3IE = 1;

    INTCONbits.MVEC = 1;   /* Multivectored */
    asm volatile ("ei");
    return (true);
}

static bool initialize_timers(void)
{
    PR1 = libsys_get_pbclk() / 256 / 102; /* 102Hz (9ms) tickrate */
                                          /* with compensation    */
    T1CON = _T1CON_ON_MASK | (0b11 << _T1CON_TCKPS_POSITION);

    date.year  = 1970;
    date.month = 1;
    date.day   = 1;
    date.day_of_week = tondering_day_of_week(&date);
    return (true);
}

static bool initialize_menu_tree(void)
{
    ITEM    *item;
    MENU    *sub1, *sub2, *sub3, *sub4;

    if (menu_new(&sub1, MENU_MAIN)) {
        if (menu_new(&sub2, MENU_HORIZONTAL)) {
            if (menu_new(&sub3, MENU_EDIT)) {
                menu_new_item(&item, ITEM_EDIT, (DESC) {
                    "Day", "" }, &date.day, 0, 2, 1, 2, 1, 31);
                menu_add_item(sub3, item);
                menu_new_item(&item, ITEM_EDIT, (DESC) {
                    "Month", "" }, &date.month, 3, 2, 1, 2, 1, 12);
                menu_add_item(sub3, item);
                menu_new_item(&item, ITEM_EDIT, (DESC) {
                    "Year", "" }, &date.year,  6, 2, 1, 4, 1, 2038);
                menu_add_item(sub3, item);
                menu_new_item(&item, ITEM_EDIT, (DESC) {
                    "Hours", "" }, &date.hours, 12, 2, 0, 2, 0, 23);
                menu_add_item(sub3, item);
                menu_new_item(&item, ITEM_EDIT, (DESC) {
                    "Minutes", "" }, &date.minutes, 15, 2, 1, 2, 0, 59);
                menu_add_item(sub3, item);
                menu_new_item(&item, ITEM_EDIT, (DESC) {
                    "Seconds", "" }, &date.seconds, 18, 2, 1, 2, 0, 59);
                menu_add_item(sub3, item);
            }
            menu_new_item(&item, ITEM_LINK, (DESC) {
                "TIME", "Set clock time." }, sub3);
            menu_add_item(sub2, item);
            if (menu_new(&sub3, MENU_VERTICAL)) {
                if (menu_new(&sub4, MENU_EDIT)) {
                }
                menu_new_item(&item, ITEM_LINK, (DESC) {
                    "Background", "Set background color." }, sub4);
                menu_add_item(sub3, item);
                if (menu_new(&sub4, MENU_EDIT)) {
                }
                menu_new_item(&item, ITEM_LINK, (DESC) {
                    "Foreground", "Set foreground color." }, sub4);
                menu_add_item(sub3, item);
                if (menu_new(&sub4, MENU_EDIT)) {
                }
                menu_new_item(&item, ITEM_LINK, (DESC) {
                    "Markers", "Set markers color." }, sub4);
                menu_add_item(sub3, item);
            }
            menu_new_item(&item, ITEM_LINK, (DESC) {
                "COLORS", "Set clock color." }, sub3);
            menu_add_item(sub2, item);
            if (menu_new(&sub3, MENU_VERTICAL)) {
                if (menu_new(&sub4, MENU_TEXT)) {
                    menu_new_item(&item, ITEM_TEXT, (DESC) {
                        "", ""} , 5, 1, "Sequence :");
                    menu_add_item(sub4, item);
                    menu_new_item(&item, ITEM_TEXT, (DESC) {
                        "", ""} , 3, 2, "TddMMYYssmmhh");
                    menu_add_item(sub4, item);
                }
                menu_new_item(&item, ITEM_LINK, (DESC) {
                    "Setting the time", "" }, sub4);
                menu_add_item(sub3, item);
                if (menu_new(&sub4, MENU_TEXT)) {
                    menu_new_item(&item, ITEM_TEXT, (DESC) {
                        "", ""} , 2, 2, "Nothing here yet");
                    menu_add_item(sub4, item);
                }
                menu_new_item(&item, ITEM_LINK, (DESC) {
                    "Bluetooth sync", "" }, sub4);
                menu_add_item(sub3, item);
                if (menu_new(&sub4, MENU_TEXT)) {
                    menu_new_item(&item, ITEM_TEXT, (DESC) {
                        "", ""} , 2, 2, "Nothing here yet");
                    menu_add_item(sub4, item);
                }
                menu_new_item(&item, ITEM_LINK, (DESC) {
                    "Changing colors", "" }, sub4);
                menu_add_item(sub3, item);
            }
            menu_new_item(&item, ITEM_LINK, (DESC) {
                "HELP", "Obtain usage advice." }, sub3);
            menu_add_item(sub2, item);
            if (menu_new(&sub3, MENU_VERTICAL)) {
                menu_new_item(&item, ITEM_HOOK, (DESC) {
                    "Toggle LCD", "Why???" }, toggle_lcd);
                menu_add_item(sub3, item);
                menu_new_item(&item, ITEM_HOOK, (DESC) {
                    "Crash Clock", "Good idea!" }, crash_clock);
                menu_add_item(sub3, item);
                menu_new_item(&item, ITEM_HOOK, (DESC) {
                    "Neopixel Hello", "Test pixels." }, pixel_hello);
                menu_add_item(sub3, item);
                menu_new_item(&item, ITEM_HOOK, (DESC) {
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

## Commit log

2016-04-03 Doc, schematic and footprint WS2812b
    [PcbLib1.PcbLib, Rain_bow_Clock.PrjPcb, Schlib1.SchLib]
2016-04-03 others docs and foot prints
    [PcbLib1.PcbLib, Schlib1.SchLib]
2016-04-21 POC LCD altium
    [Neo_Pixel.PrjPCB, PCB_Project.PrjPcb, Sheet1.SchDoc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]
2016-04-25 poc serial in led
    [Main_sheet.SchDoc, Schlib1.SchLib]
2017-04-27 As constructed
    [Bill of Materials.xls, Bluetooth.SchDoc, Board.PcbDoc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]
2017-04-27 last update
    [I2C_BMP280.SchDoc, LCD.PrjPcb, LCD.SchDoc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]
